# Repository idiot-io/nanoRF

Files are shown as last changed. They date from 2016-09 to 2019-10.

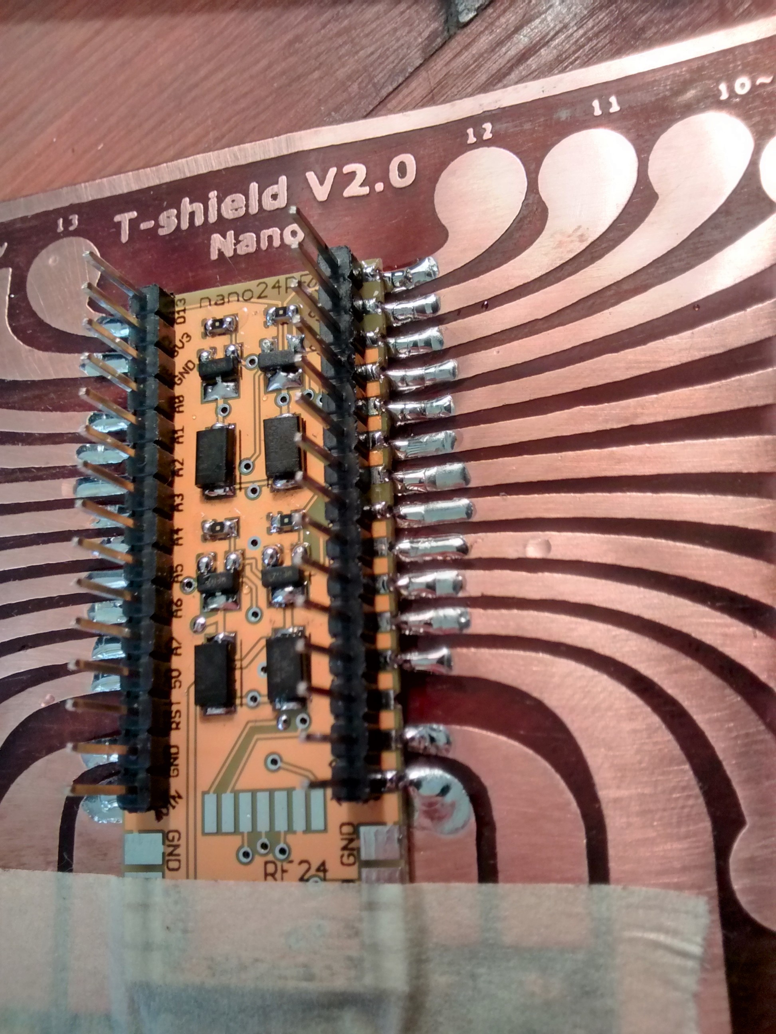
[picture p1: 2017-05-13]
Media/nanorf.jpg

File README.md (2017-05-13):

# nano24rf

should look something like this with nano on top, here is rev3, waiting for rev4 board to arrive from elecrow


  

##galleries
[Tshield nano24RF - pcb ver2](https://goo.gl/photos/zeQ4RWo6FQgi1pi57)  
[Tshield nano24RF - etching](https://goo.gl/photos/ZEXhPJtmmUaZaXrM9)

##rev4



##rev3


##rev2




##REV1




##sketch 0




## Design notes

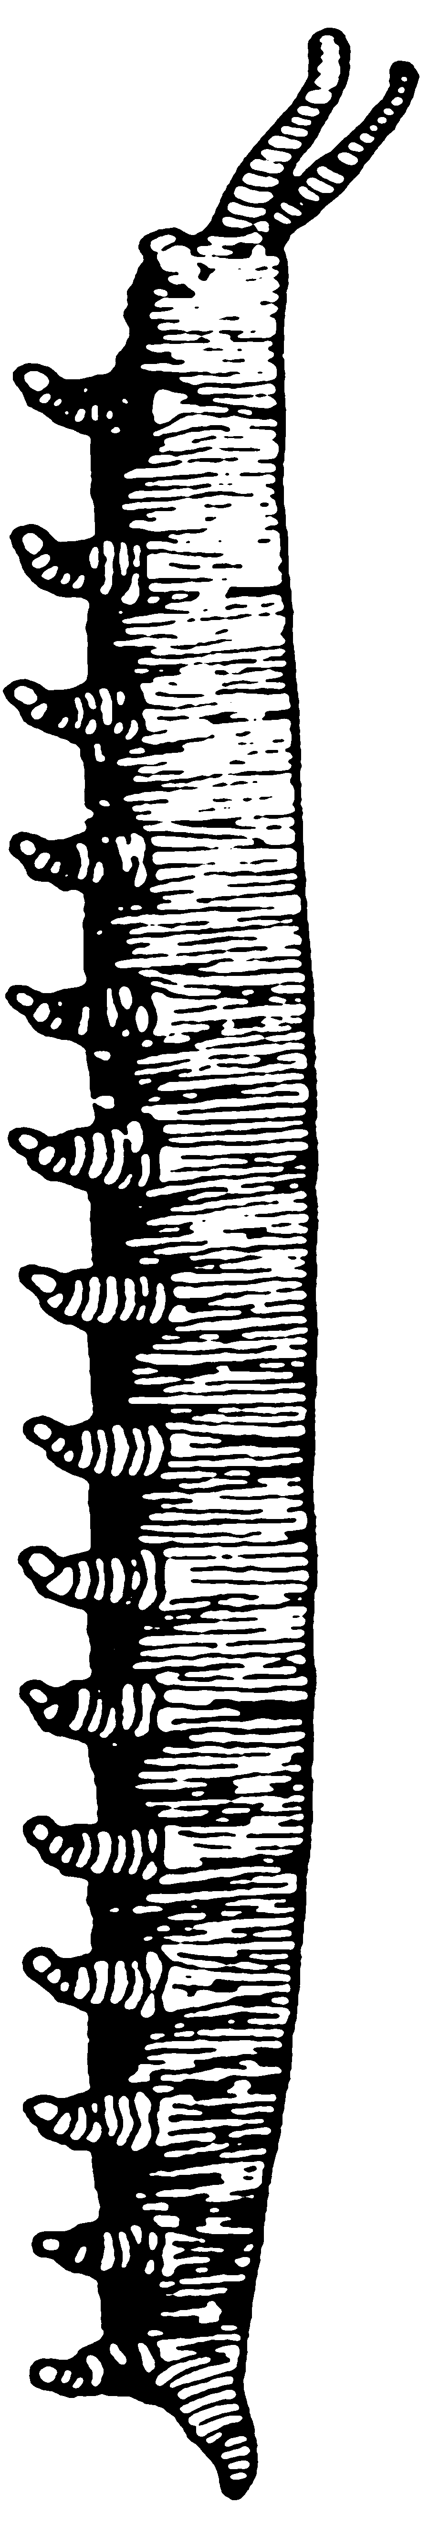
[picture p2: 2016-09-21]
board/silk/worm.png

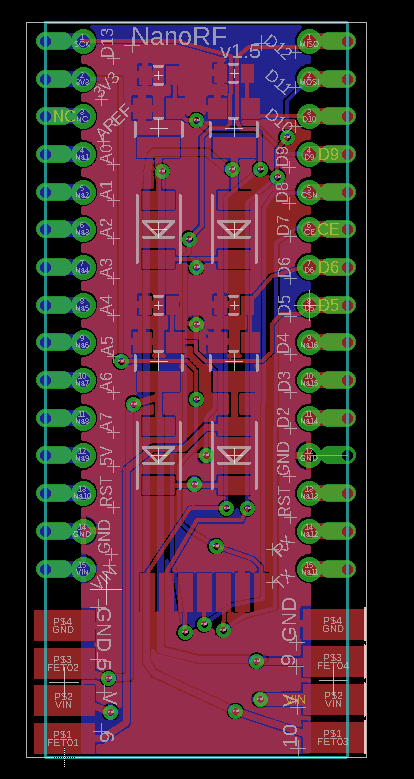
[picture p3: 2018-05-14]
board/nanoRF-board.png

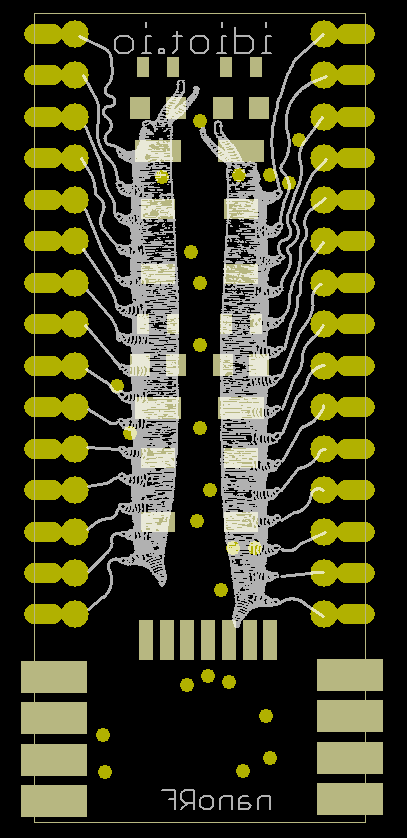
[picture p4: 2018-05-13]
board/nanoRF-board_back.png

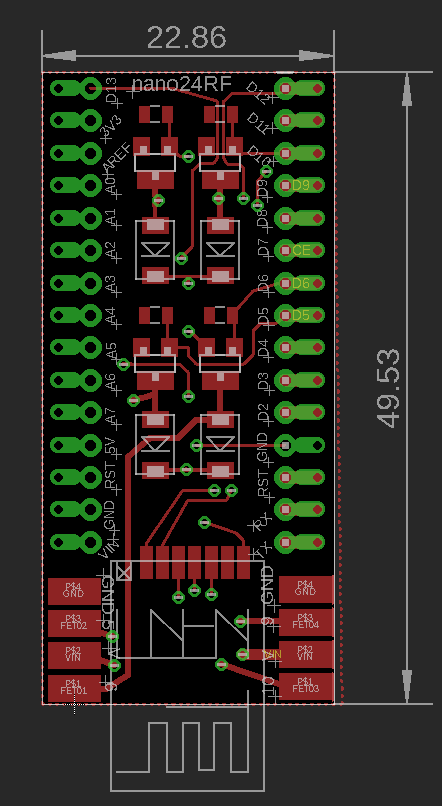
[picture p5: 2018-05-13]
board/nanoRF-board`-noEdge.png

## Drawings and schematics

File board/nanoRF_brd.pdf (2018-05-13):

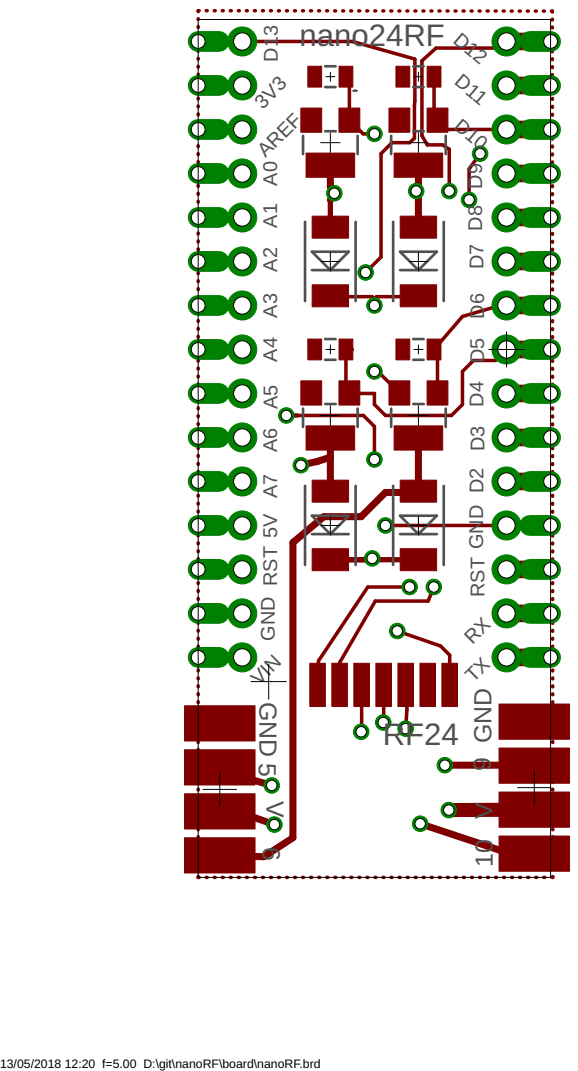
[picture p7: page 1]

13/05/2018 12:20 f=5.00 D:\git\nanoRF\board\nanoRF.brd

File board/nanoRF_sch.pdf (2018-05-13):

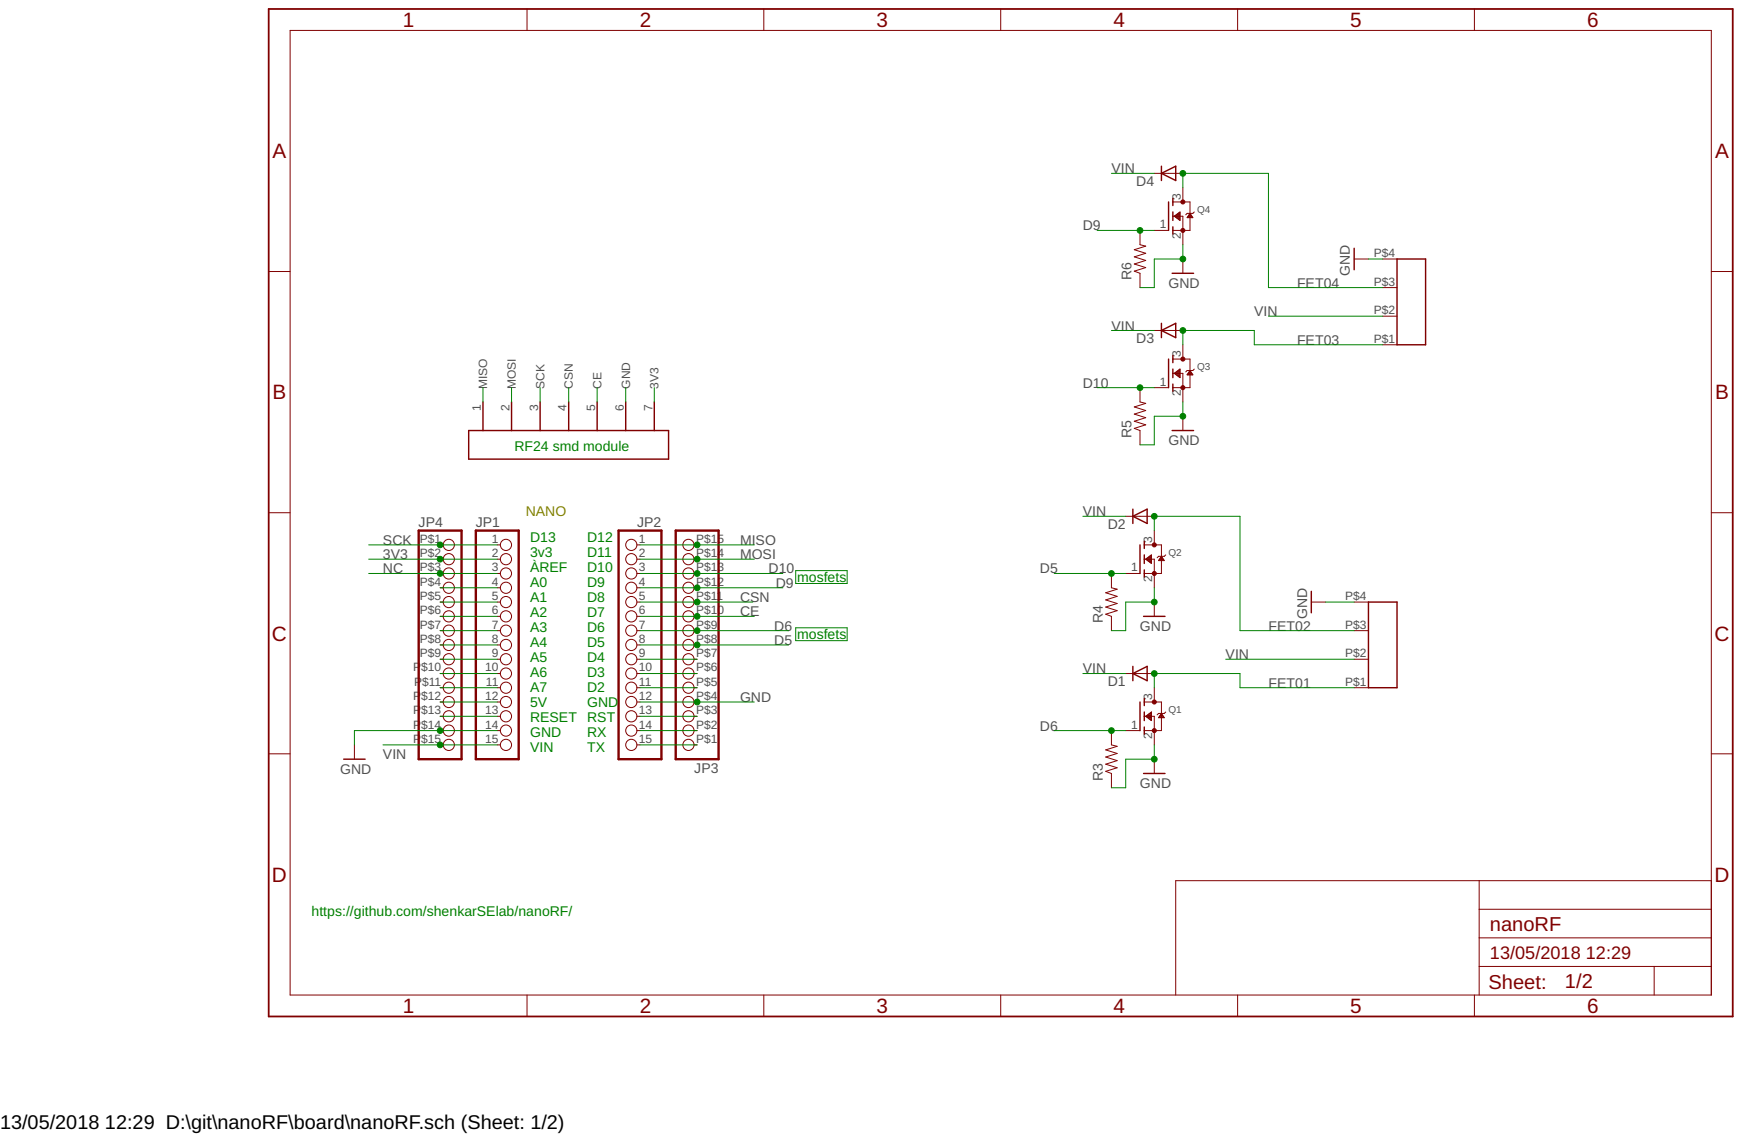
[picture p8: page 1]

https://github.com/shenkarSElab/nanoRF/

13/05/2018 12:29 D:\git\nanoRF\board\nanoRF.sch (Sheet: 1/2)

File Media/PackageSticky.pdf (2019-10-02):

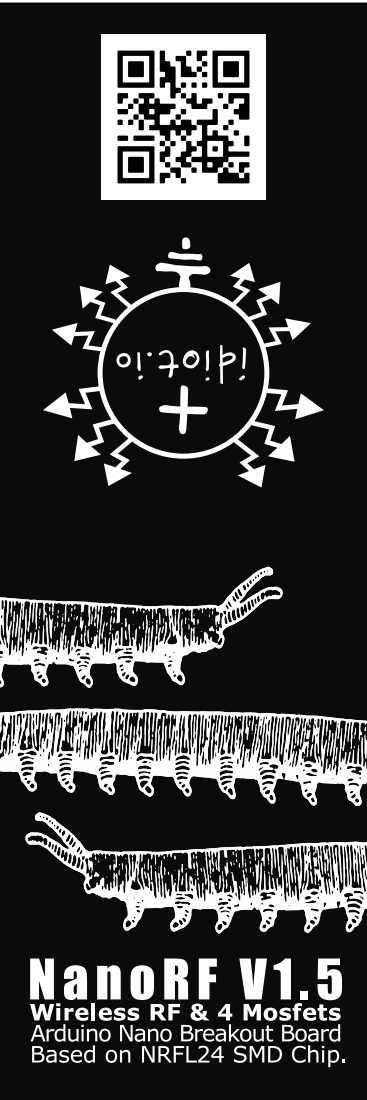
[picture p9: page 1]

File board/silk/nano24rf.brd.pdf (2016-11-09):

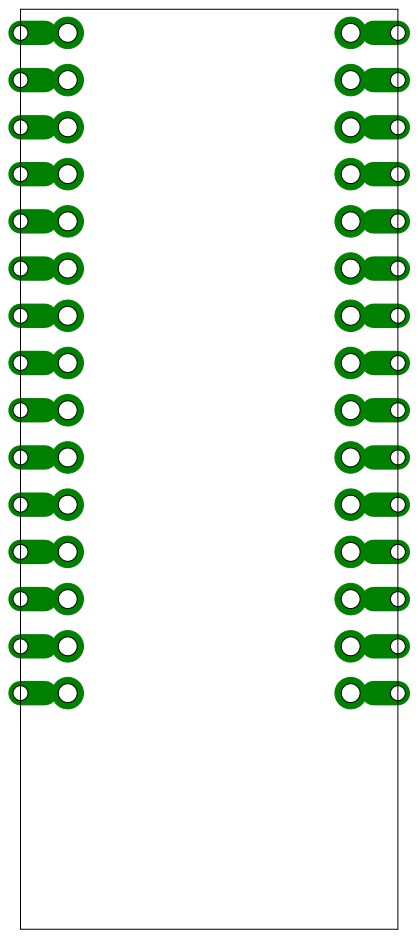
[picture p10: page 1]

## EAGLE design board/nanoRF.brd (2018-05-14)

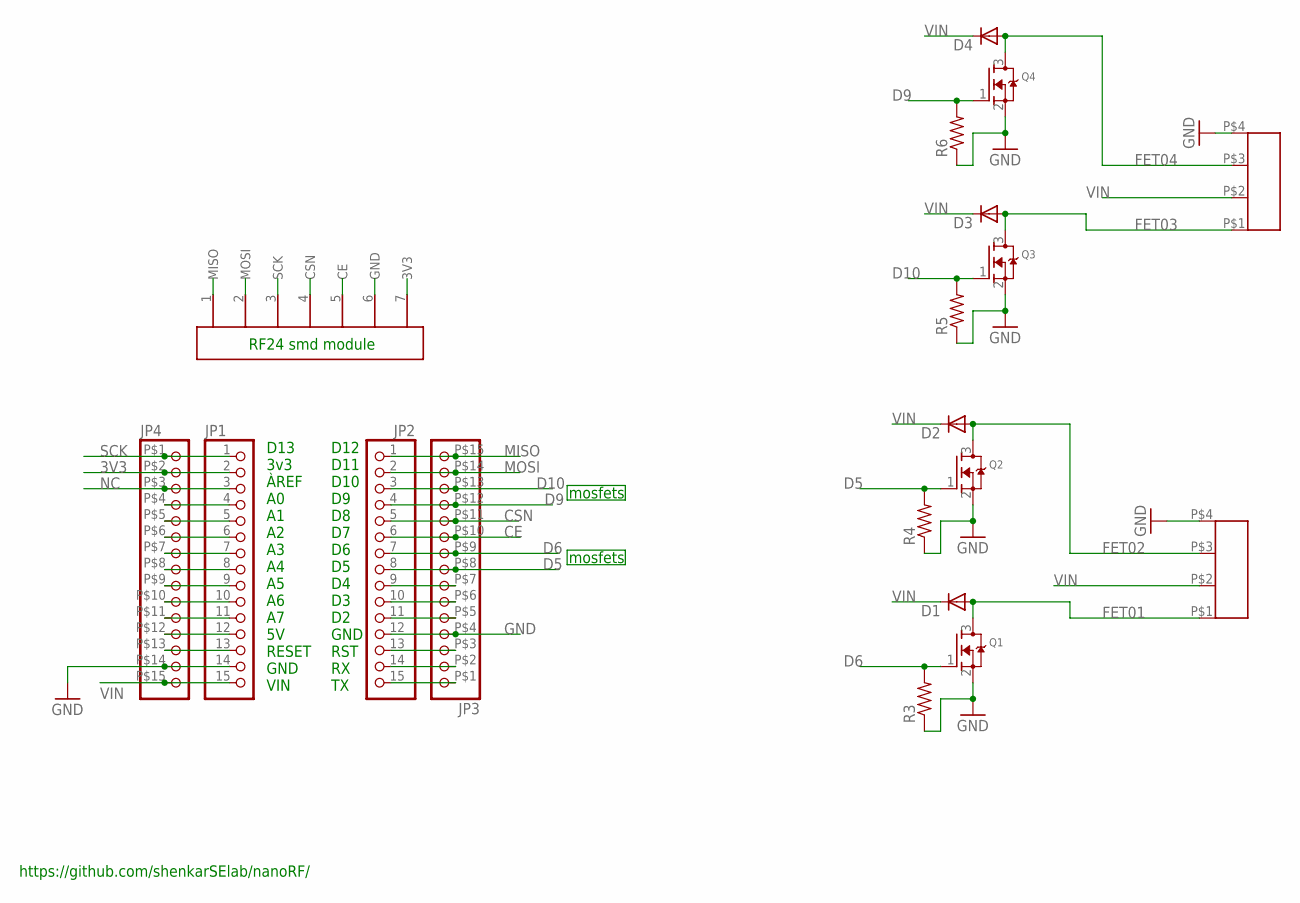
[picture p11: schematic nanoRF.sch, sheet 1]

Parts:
D1, D2, D3, D4: DIODE-DO-214AC; DO-214AC
JP1, JP2: HEADER-1X15RND; 1X15_ROUND_70
JP3, JP4: HEADER-1X15LONG; 1X15_LONG
MOSFET-12, MOSFET-34: FATPAD4LONG; FATFAD4-LONG
Q1, Q2, Q3, Q4: MOSFET-NWAVE; SOT23-W
R3, R4, R5, R6: RESISTOR0805-RES; 0805
RF24: 1X7-SMDPADS; SMD1,27-2,54

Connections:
3V3: JP1.2, JP4.P$2 (2), RF24.7 (3V3)
CE: JP2.6, JP3.P$10 (10), RF24.5 (CE)
CSN: JP2.5, JP3.P$11 (11), RF24.4 (CSN)
D5: JP2.8, JP3.P$8 (8), Q2.1 (G), R4.2
D6: JP2.7, JP3.P$9 (9), Q1.1 (G), R3.2
D9: JP2.4, JP3.P$12 (12), Q4.1 (G), R6.2
D10: JP2.3, JP3.P$13 (13), Q3.1 (G), R5.2
FET01: D1.2 (A), MOSFET-12.P$1, Q1.3 (D)
FET02: D2.2 (A), MOSFET-12.P$3, Q2.3 (D)
FET03: D3.2 (A), MOSFET-34.P$1, Q3.3 (D)
FET04: D4.2 (A), MOSFET-34.P$3, Q4.3 (D)
GND: JP1.14, JP2.12, JP3.P$4 (4), JP4.P$14 (14), MOSFET-12.P$4, MOSFET-34.P$4, Q1.2 (S), Q2.2 (S), Q3.2 (S), Q4.2 (S), R3.1, R4.1, R5.1, R6.1, RF24.6 (GND)
MISO: JP2.1, JP3.P$15 (15), RF24.1 (MISO)
MOSI: JP2.2, JP3.P$14 (14), RF24.2 (MOSI)
unnamed: JP1.4, JP4.P$4 (4)
unnamed: JP1.5, JP4.P$5 (5)
unnamed: JP1.6, JP4.P$6 (6)
unnamed: JP1.7, JP4.P$7 (7)
unnamed: JP1.8, JP4.P$8 (8)
unnamed: JP1.9, JP4.P$9 (9)
unnamed: JP1.10, JP4.P$10 (10)
unnamed: JP1.11, JP4.P$11 (11)
unnamed: JP1.12, JP4.P$12 (12)
unnamed: JP1.13, JP4.P$13 (13)
unnamed: JP2.15, JP3.P$1 (1)
unnamed: JP2.14, JP3.P$2 (2)
unnamed: JP2.13, JP3.P$3 (3)
unnamed: JP2.11, JP3.P$5 (5)
unnamed: JP2.10, JP3.P$6 (6)
unnamed: JP2.9, JP3.P$7 (7)
NC: JP1.3, JP4.P$3 (3)
SCK: JP1.1, JP4.P$1 (1), RF24.3 (SCK)
VIN: D1.1 (C), D2.1 (C), D3.1 (C), D4.1 (C), JP1.15, JP4.P$15 (15), MOSFET-12.P$2, MOSFET-34.P$2

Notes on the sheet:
D12 D11 D10 D9 D8 D7 D6 D5 D4 D3 D2 GND RST RX TX
D13 3v3 ÀREF A0 A1 A2 A3 A4 A5 A6 A7 5V RESET GND VIN
https://github.com/shenkarSElab/nanoRF/
mosfets
RF24 smd module

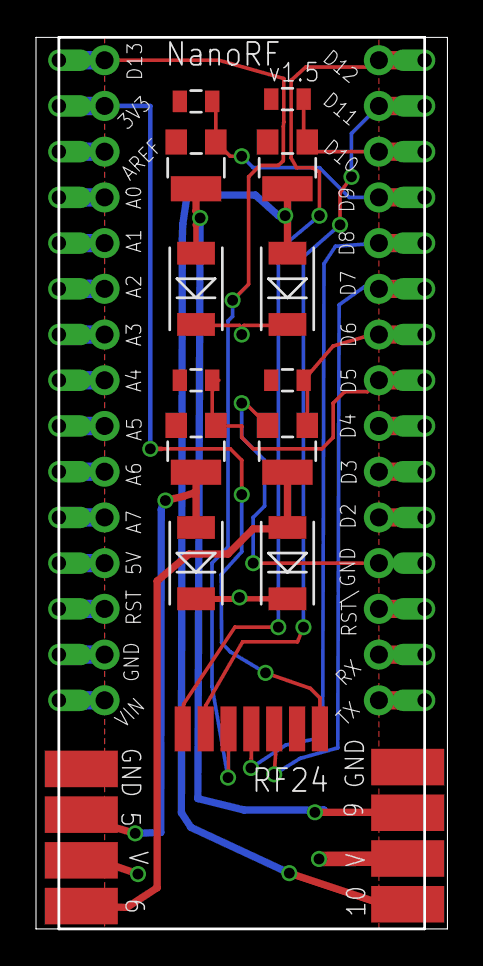
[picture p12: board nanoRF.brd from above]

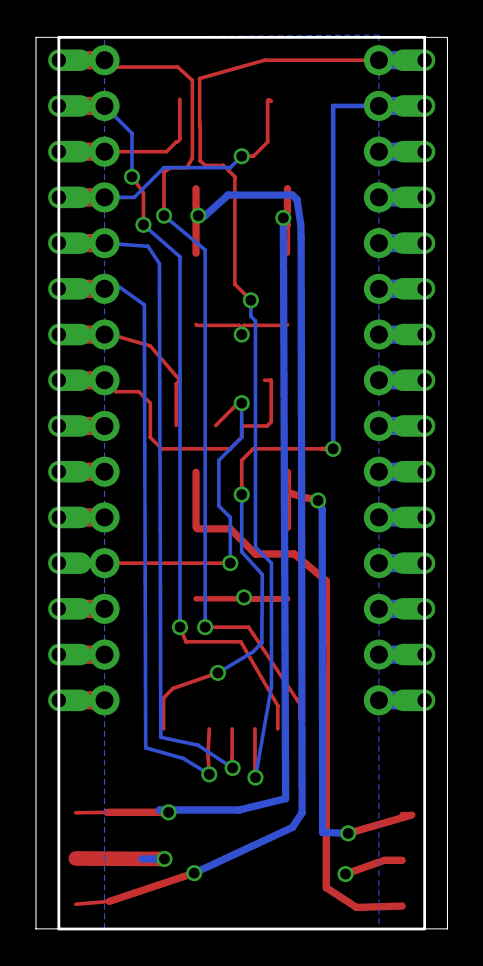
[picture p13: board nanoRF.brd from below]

Board: 2 copper layers, 22.9 x 49.5 mm, 19 parts (3 on the bottom side), 33 nets.

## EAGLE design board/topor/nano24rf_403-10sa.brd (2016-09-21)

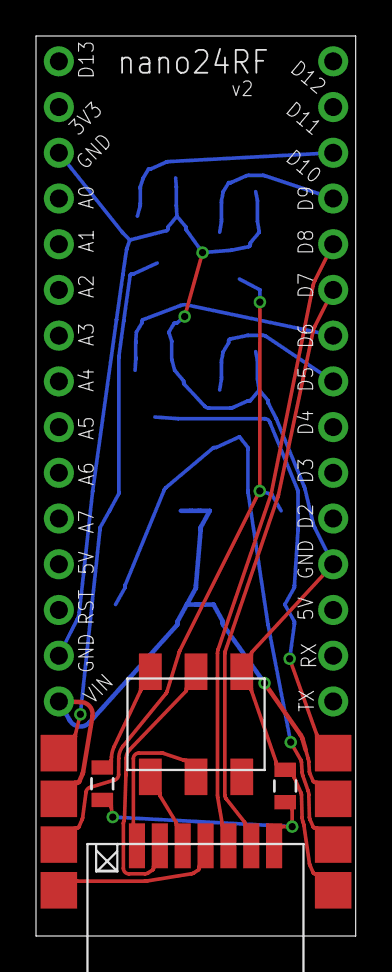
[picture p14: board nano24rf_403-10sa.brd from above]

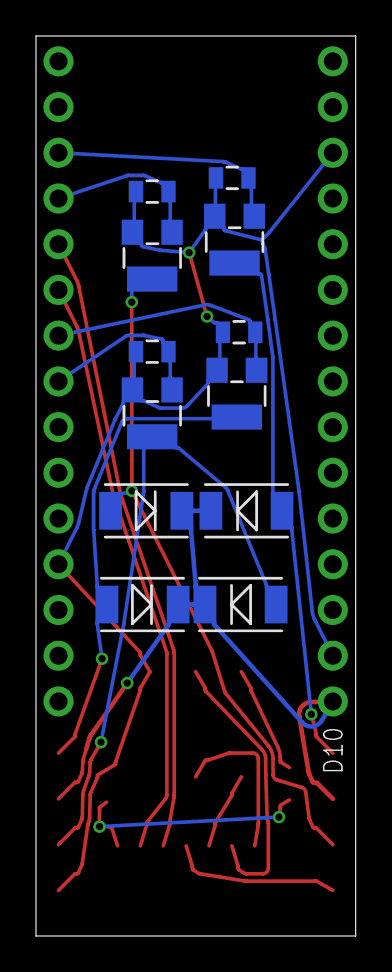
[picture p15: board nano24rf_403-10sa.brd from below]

Board: 2 copper layers, 17.8 x 50.0 mm, 20 parts (12 on the bottom side), 18 nets.

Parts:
D1, D2, D3, D4: DO-214AC
JP1, JP2: 1X15_ROUND_70
JP3: 2X03_SMT
Q1, Q2, Q3, Q4: SOT23-W
R1, R2, R3, R4, R5, R6: 0805
U$6, U$8: FATPAD4
U$7: SMD1,27-2,54

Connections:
5V: JP3.2, R1.1
CE: JP2.6, U$7.2
CSN: JP2.5, U$7.3
D5: JP2.8, Q2.1, R4.2
D6: JP2.7, Q1.1, R3.2
D9: JP2.4, Q4.1, R6.2
D10: JP2.3, Q3.1, R5.2
FET01: D1.2, Q1.3, U$8.P$1
FET02: D2.2, Q2.3, U$8.P$3
FET03: D3.2, Q3.3, U$6.P$1
FET04: D4.2, Q4.3, U$6.P$3
GND: JP1.3, JP1.14, JP2.12, JP3.6, Q1.2, Q2.2, Q3.2, Q4.2, R2.1, R3.1, R4.1, R5.1, R6.1, U$8.P$4
MISO: JP3.1, U$7.5
MOSI: JP3.4, U$7.6
unnamed: R1.2, R2.2, U$7.1
S$1: U$6.P$4, U$7.4
SCK: JP3.3, U$7.7
VIN: D1.1, D2.1, D3.1, D4.1, JP1.15, U$6.P$2, U$8.P$2

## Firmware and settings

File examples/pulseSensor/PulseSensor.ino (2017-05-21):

/*
   15/05/2017 - interrupt changes by zohar mf from shenkar SE lab for the Tshield wearable kit
   https://github.com/shenkarSElab/nanoRF

   Based on Joel Murphy and Yury Gitman's Pulse Sensor code
   [see 6431f00  revisions for full License]
*/

#include "PulseSensorBPM.h"

///////////// RF24 RADIO code ////////////
#include <SPI.h>
#include "RF24.h"
byte addresses[][6] = {"1Node", "2Node"};
typedef enum { role_ping_out = 1, role_pong_back } role_e;                 // The various roles supported by this sketch
role_e role ;

/* Hardware configuration: Set up nRF24L01 radio on SPI bus plus pins 7 & 8 */
RF24 radio(7, 8);
#define role_pin A3

struct dataStruct {
  unsigned long _micros;
  int BPM;
  int IBI;
} myData;
/////////////////////////////////////////

/*
   Pinout:
     HAS_A_REF = set to true if you have connected
       the pulse sensor power pin to A-REF.
       If you are powering the pulse sensor below 5V,
       you must set HAS_A_REF to true.
     PIN_INPUT = Analog Input. Connected to the pulse sensor
      purple (signal) wire.
     PIN_BLINK = digital Output. Connected to an LED (and 220 ohm resistor)
      that will flash on each detected pulse.
     PIN_FADE = digital Output. Connected to an LED (and resistor)
      that will smoothly fade with each pulse.
*/
const boolean HAS_A_REF = false;
const int PIN_INPUT = A0;
const int PIN_BLINK = 4;    // Pin 4
const int PIN_FADE = 5;      // must be a pin that supports PWM. Can't be pin 9 or 10 (see ISR()).

/*
   Planned time (microseconds) between calls to readSensor().
   Note: interruptSetup() assumes this value is 2 milliseconds (2000 microseconds).
*/
const unsigned long MICROS_PER_READ = 2 * 1000L;

// PWM steps per fade step.  More fades faster; less fades slower.
const int PWM_STEPS_PER_FADE = 12;

/*
   fadePWM = Pulse Width Modulation value for our fading LED
   (0 = off; 255 = full on)
*/
int fadePWM;

/*
   The per-sample processing code.
*/
PulseSensorBPM pulseDetector(PIN_INPUT, MICROS_PER_READ / 1000L);

/*
   If true, we've seen a beat that hasn't yet been printed.
   Set in the ISR.
   Cleared in loop().
*/
volatile boolean QS;

void setup() {
  //Use 115200 baud
  Serial.begin(115200);


  radio.begin();
  // Open a writing and reading pipe on each radio, with opposite addresses
  pinMode(role_pin, INPUT);
  digitalWrite(role_pin, HIGH);
  delay(20); // Just to get a solid reading on the role pin
  // read the address pin, establish our role

  if ( digitalRead(role_pin) ) {
    role = role_pong_back;

    radio.openWritingPipe(addresses[1]);
    radio.openReadingPipe(1, addresses[0]);
    radio.startListening();

    // PIN_INPUT is set up by the pulseDetector constructor.
    pinMode(PIN_BLINK, OUTPUT);
    digitalWrite(PIN_BLINK, LOW);

    pinMode(PIN_FADE, OUTPUT);
    fadePWM = 0;
    analogWrite(PIN_FADE, fadePWM);   // sets PWM duty cycle

    Serial.println("i receive data");
  } else {
    role = role_ping_out;

    radio.openWritingPipe(addresses[0]);
    radio.openReadingPipe(1, addresses[1]);
    radio.stopListening();

    Serial.println("i send data");
  }

  QS = false;
  interruptSetup(); // start the interrupt timer.
}

void loop() {

  delay(20);

  if (role == role_ping_out)
  { //sender
    Serial.print('S');
    Serial.println(pulseDetector.getSignal());
    /*
      Serial.print('P');
      Serial.println(pulseDetector.isPulse());
      Serial.print('I');
      Serial.println(pulseDetector.getIBI());
    */
    // If the ISR has seen a beat, print the per-beat information.
    if (QS) {
      Serial.println();
      Serial.print('B');
      Serial.println(pulseDetector.getBPM());

      myData.BPM = pulseDetector.getBPM();
      //myData.IBI = pulseDetector.getIBI();
      bool ok = radio.write( &myData, sizeof(myData) );
      QS = false;
    }

  }
  else if ( role == role_pong_back )
  { //receiver

    unsigned long started_waiting_at = micros();               // Set up a timeout period, get the current microseconds
    boolean timeout = false;                                   // Set up a variable to indicate if a response was received or not

    while ( ! radio.available() ) {                            // While nothing is received
      if (micros() - started_waiting_at > 200000 ) {           // If waited longer than 200ms, indicate timeout and exit while loop
        timeout = true;
        //Serial.println("timeout");
        digitalWrite(PIN_BLINK, HIGH);
        break;
      }
    }

    if ( radio.available()) {
      // Variable for the received timestamp
      while (radio.available()) {                          // While there is data ready
        radio.read( &myData, sizeof(myData) );             // Get the payload
        fadePWM = 255;  // start fading on the start of each beat.
        //Blink the non-fading LED when the start of a pulse is detected.
        int bpmIn = myData.BPM;
        if (bpmIn < 100) {
          Serial.print('B');
          Serial.println(bpmIn);

          digitalWrite(PIN_BLINK, LOW);
        }
      }
      /*
        Serial.print('Q');
        Serial.println(myData.IBI);
        if (myData.BPM>80)
      	HIGHbpm();
        if (myData.BPM<78)
      	LOWbpm();
      */
    }
    /*
      // Coincidentally, fade the LED a bit.
      fadePWM -= PWM_STEPS_PER_FADE;
      if (fadePWM < 0) {
    	fadePWM = 0;
      }
      analogWrite(PIN_FADE, fadePWM);
    */
  }

}

void HIGHbpm() {
  Serial.println(" HIGH BPM ");
  //put your code here
}
void LOWbpm() {
  Serial.println(" LOW BPM ");
  //put your code here
}


/*
   Sets up a Timer Interrupt for every 2ms
*/
void interruptSetup() {
  // Initializes Timer1 to throw an interrupt every 2mS.
  TCCR1A = 0x00; // DISABLE OUTPUTS AND BREAK PWM ON DIGITAL PINS 9 & 10
  TCCR1B = 0x11; // GO INTO 'PHASE AND FREQUENCY CORRECT' MODE, NO PRESCALER
  TCCR1C = 0x00; // DON'T FORCE COMPARE
  TIMSK1 = 0x01; // ENABLE OVERFLOW INTERRUPT (TOIE1)
  ICR1 = 16000;   // TRIGGER TIMER INTERRUPT EVERY 1mS
  sei();         // MAKE SURE GLOBAL INTERRUPTS ARE ENABLED
}

//Read more: http://pulsesensor.proboards.com/thread/144/using-timer1-timer2-free-pin#ixzz4glL7U0zB
// THIS IS THE TIMER 1 INTERRUPT SERVICE ROUTINE.
// Timer 1 makes sure that we take a reading every 2 miliseconds
ISR(TIMER1_OVF_vect) {                   // triggered when Timer1 counts to 124
  cli();                                   // disable interrupts while we do this
  if (pulseDetector.readSensor()) {
    QS = true;
  }
  sei();                                   // enable interrupts when youre done!
}// end isr

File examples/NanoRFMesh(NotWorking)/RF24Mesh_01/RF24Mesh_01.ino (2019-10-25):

/** RF24Mesh_Example.ino by TMRh20

   This example sketch shows how to manually configure a node via RF24Mesh, and send data to the
   master node.
   The nodes will refresh their network address as soon as a single write fails. This allows the
   nodes to change position in relation to each other and the master node.
*/
//SYSTEM V2.5

#include "RF24.h"
#include "RF24Network.h"
#include "RF24Mesh.h"
#include <SPI.h>


int LED = 6;    // PWM Pin  6


/**** Configure the nrf24l01 CE and CS pins ****/
RF24 radio(10, 9);//NanoRF (7,8)
RF24Network network(radio);
RF24Mesh mesh(radio, network);

/**
   User Configuration: nodeID - A unique identifier for each radio. Allows addressing
   to change dynamically with physical changes to the mesh.

   In this example, configuration takes place below, prior to uploading the sketch to the device
   A unique value from 1-255 must be configured for each node.
   This will be stored in EEPROM on AVR devices, so remains persistent between further uploads, loss of power, etc.

 **/
#define nodeID 1//SYSTEM V2.5


uint32_t displayTimer = 0;

struct payload_t {
  unsigned long ms;
  unsigned long counter;
};

struct dataStruct1 {
  int vA1, vB1, vC1, LvibMSG; // 6 Electrodes Values
} myData;

void setup() {
  pinMode(LED, OUTPUT);
  digitalWrite(LED, LOW);

  Serial.begin(115200);

  // Set the nodeID manually
  mesh.setNodeID(nodeID);
  // Connect to the mesh
  Serial.println(F("Connecting to the mesh..."));
  mesh.begin();
}

void loop() {

  mesh.update();

  // Send to the master node every second
  if (millis() - displayTimer >= 100) {
    displayTimer = millis();
    myData.vA1 = analogRead(A0);
    myData.vB1 = analogRead(A1);
    myData.vC1 = analogRead(A2);

    if ( myData.LvibMSG != 0) {
      digitalWrite(LED, HIGH);
    } else {
      digitalWrite(LED, LOW);
      myData.LvibMSG = 0;
    }

    // Send an 'M' type message containing the current millis()
    if (!mesh.write(&myData, 'M', sizeof(myData))) {

      // If a write fails, check connectivity to the mesh network
      if ( ! mesh.checkConnection() ) {
        //refresh the network address
        Serial.println("Renewing Address");
        if (!mesh.renewAddress()) {
          //If address renewal fails, reconfigure the radio and restart the mesh
          //This allows recovery from most if not all radio errors
          mesh.begin();
        }
      } else {
        Serial.println("Send fail, Test OK");
      }
    } else {
      Serial.print("Send OK: "); 
      Serial.println(displayTimer);
      Serial.print( myData.vA1); Serial.print(",");
      Serial.print( myData.vB1); Serial.print(",");
      Serial.print( myData.vC1); Serial.print(",");
      Serial.println( myData.LvibMSG);
    }
  }

  while (network.available()) {
    RF24NetworkHeader header;
        payload_t payload;
        network.read(header, &payload, sizeof(payload));
        Serial.print("Received packet #");
        Serial.print(payload.counter);
        Serial.print(" at ");
        Serial.println(payload.ms);
 
  }

}

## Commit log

2016-05-22 add schmea file, empty
    [nano24rf.sch]
2016-05-22 add https://github.com/cyberlink1/Arduino-Eagle-Cad-Library
2016-05-22 added arduino clone lib submodule
2016-05-22 start work on sch/brd
    [nano24rf.sch]
2016-05-22 with mini for lols
    [nano24rf.sch]
2016-05-22 remove Arduino ealecad
2016-05-23 pushed around
    [nano24rf.brd, nano24rf.sch]
2016-05-23 more jump
    [nano24rf.brd, nano24rf.sch]
2016-05-25 add pdf, review ver
    [nano24rf.brd, nano24rf.sch]
2016-05-25 rotate labels
    [nano24rf.brd, nano24rf.sch]
2016-05-25 ready for raw jumoper"
    [nano24rf.brd, nano24rf.sch]
2016-05-28 removed lm317 and placed msfets on bottom
    [nano24rf.brd, nano24rf.sch]
2016-05-31 before reomval of swith for fnr24
    [nano24rf.brd, nano24rf.sch]
2016-05-31 more output
    [nano24rf.brd, nano24rf.sch]
2016-06-01 gerber script and bom
    [Proj1.GBL, Proj1.GBO, Proj1.GBP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]
2016-08-04 before route
    [nano24rf.brd, nano24rf.sch]
2016-08-04 fix placment or resistors
    [nano24rf-top.brd]
2016-08-04 added lib, need to fix volt div placment
    [nano24rf.brd, nano24rf.sch]
2016-08-16 ready to grb
    [nano24rf-top.brd, nano24rf-topo.brd, nano24rf.brd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]
2016-08-18 added bom
    [nano24rf-BOM.tsv]
2016-09-20 some topo
    [nano24rf-topo.brd]
2016-09-20 added FATPAD4
    [nano24rf-topo.brd, nano24rf.brd, nano24rf.sch]
2016-09-20 after topor
    [nano24rf-topo.brd, nano24rf.brd]
2016-09-20 panelized and added sparkfun lipo xchrger
    [nano24rf-topo.brd, nano24rf-topo2.brd]
2016-09-21 worm added
    [Proj1.GBL, Proj1.GBO, Proj1.GBP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]
2016-09-21 added top mosfets, cant use cuz highet
    [nano24rf-topo-thru.brd]
2016-09-21 another go on the topoR
    [nano24rf-topo-thru.brd, nano24rf.brd, nano24rf_403-10sa.brd]
2016-09-22 added gerber worm
    [nano24rf_403-10sa.GBL, nano24rf_403-10sa.GBO, nano24rf_403-10sa.GBP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]
2016-09-22 sent to elecrow order #42345
    [nano24.GBL, nano24.GBO, nano24.GBP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]
2016-09-22 some more cleaning
    [nano24rf-topo-panelized.brd, worm.brd]
2016-09-22 added GML gerber file for sub-board cuts
2016-10-17 fixed bad packges for 2x3 and smdx07
    [nano24rf-BOM.csv, nano24rf.brd, nano24rf.sch]
2016-10-20 routed ver3, no canstlation
    [nano24rf.brd, nano24rf.sch]
2016-10-21 added gerber for cestlation fike
    [nano24rf.GBL, nano24rf.GBO, nano24rf.GBP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]
2016-10-21 back to round ads
    [nano24rf.brd, nano24rf.sch]
2016-10-21 long pads
    [nano24rf.brd, nano24rf.sch]
2016-10-21 slight schema re-arange, and gerber
    [nano24rf.brd, nano24rf.sch]
2016-10-25 switched to pin11 one of the mosfet
    [nano24rf.brd, nano24rf.sch]
2016-10-25 removed SPI
    [nano24rf.brd, nano24rf.sch]
2016-10-25 re-routed D10 to MOSFET
    [nano24rf.brd, nano24rf.sch]
2016-10-25 SCK reouted, and shoved nrf24 inside
    [nano24rf.brd, nano24rf.sch]
2016-10-25 new gerber for slim design
    [nano24.GBL, nano24.GBO, nano24.GBP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]
2016-10-25 back to plated edge
    [nano24rf.brd, nano24rf.sch]
2016-10-27 silkscreen bahh
    [nano24rf.brd]
2017-01-31 pushed cneter parts back
    [nano24rf.brd]
2017-01-31 board export
    [ATtami.GBL, ATtami.GBS, ATtami.GTL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]
2017-02-06 refined edges
    [nano24rf.brd, nano24rf.sch]
2017-02-06 removed extra layers
    [nano24rf.brd]
2017-02-10 sent for price quete
    [nano24rf -panel.GBL, nano24rf -panel.GBO, nano24rf -panel.GBP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]
2017-02-12 non castlated version
    [nano24rf.GBL, nano24rf.GBO, nano24rf.GBP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]
2017-05-15 added example folder, with pulse sensor code
2017-05-15 working with timer1
2017-05-17 changed prj name and files to nanoRF, starting fix for AREF pin
    [Proj1.GBL, Proj1.GBO, Proj1.GBP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]
2017-05-17 fixed Aref pin horror
    [nanoRF.brd, nanoRF.sch]
2017-05-17 added interrupt explain, reducted comments
2017-05-20 removed reset and aref
    [nanoRF.brd, nanoRF.sch]
2017-05-20 gerber no edge
2017-05-20 moved corner to 0,0
    [nanoRF.brd]
2017-05-20 added gerber edge
2017-05-20 added noEdge
    [nanoRF.brd]
2018-05-13 revert to green ver, with gnd fix
    [nanoRF.brd, nanoRF.sch]
2018-05-13 added schema
    [nanoRF.sch]
2018-05-13 gerber for edge
    [nanoRF.brd]
2018-05-13 noEdge design, with gerber files
    [nanoRF.brd]
2018-05-14 no edge v1.5
    [nanoRF.brd]
2018-05-14 new cam, both cutouts
    [nanoRF.brd]
2018-05-14 board png
2018-05-16 approved singlee boards for fab
    [grb-nanoRF.cfg]
2019-03-20 30us jitter, same channel
    [MultiTxAckPayload.ino, SimpleRxAckPayload.ino]
